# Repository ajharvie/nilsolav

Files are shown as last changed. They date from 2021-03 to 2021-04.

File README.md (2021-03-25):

# Nils Olav
A simple-to-build, low-profile, ortholinear keyboard named after a [famous penguin.](https://en.wikipedia.org/wiki/Nils_Olav) This keyboard is based around the Elite-C v4. It features a left-sided numpad, (useful for design work), 2U spacebar, a cute little penguin, and as low a parts count as possible to make it easy for individuals to build with very simple soldering tools.

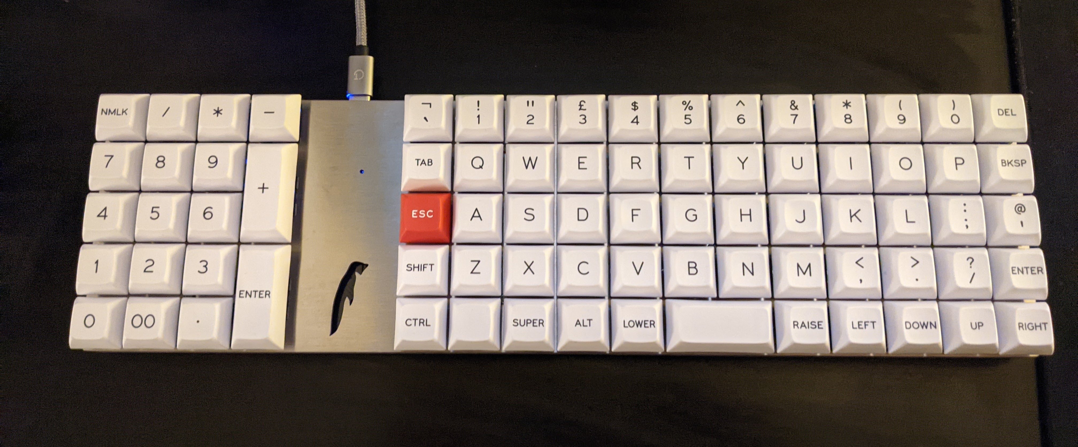
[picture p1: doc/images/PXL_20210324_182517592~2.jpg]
Image of keyboard


[A pre-compiled firmware hex](firmware/nilsolav_default.hex) (nilsolav_default.hex) is provided for my slightly unusual default keymap ([shown here](firmware/nilsolav/keymaps/default/keymap.c)). QMK users who wish to build their own keymap can do so using the source code provided in the [firmware](firmware) folder.

In the default keymap, double-tapping the numlock key toggles a layer where the numpad is transformed into a nav cluster.

Parts needed:
* PCB x1
* Bottom plate x1 
* Top plate x1 (1.5 mm thick)
* 8mm M2 standoffs x7
* M2 screws x14 (length depends on bottom plate thickness)
* Elite C v4 x1
* 2U stabiliser x1
* SOD-123 SMD diodes x77
* Your choice of MX switches x77
* Keycaps

[A build guide is included here.](doc/buildguide.md)

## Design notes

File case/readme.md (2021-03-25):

.dxf files for top and bottom plates that comprise the simple sandwich case. Mine is cut out of 3 mm brushed steel for the bottom plate, and 1.5 mm brushed steel for the top. 

To complete the case, you'll need some 8 mm (or longer) M2 standoffs, and 14 M2 screws (I used 7 x 4 mm and 7 x 6 mm)

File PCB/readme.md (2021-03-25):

KiCad files and gerbers for the keyboard. If you just want to make the keyboard PCBs, you just need the .zip of gerbers. I used PCBway but there are many good options for manufacturers.

If you're going to edit the pcb files, you'll need the following libraries:

ai03's MX footprint libary: https://github.com/ai03-2725/MX_Alps_Hybrid
Keebio-parts: https://github.com/keebio/Keebio-Parts.pretty
ai03's random-keyboard-parts: https://github.com/ai03-2725/random-keyboard-parts.pretty

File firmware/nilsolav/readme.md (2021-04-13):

# Nils Olav
A simple-to-build, low-profile, ortholinear keyboard named after a famous penguin. This keyboard is based around the Elite-C v4. It features a left-sided numpad, (useful for design work), 2U spacebar, and as low a parts count as possible to make it easy for individuals to build with very simple soldering tools.

Github repo with parts and build instructions: https://github.com/ajharvie/nilsolav

Parts needed:
* PCB x1
* Bottom plate x1 (I used 3 mm steel)
* Top plate x1 (1.5 mm thick)
* 8mm M2 standoffs x7
* M2 screws x14 (length depends on bottom plate thickness)
* Elite C v4 x1 (with castellated holes)
* 2U stabiliser x1
* SOD-123 SMD diodes x77
* Your choice of MX switches x77
* Keycaps

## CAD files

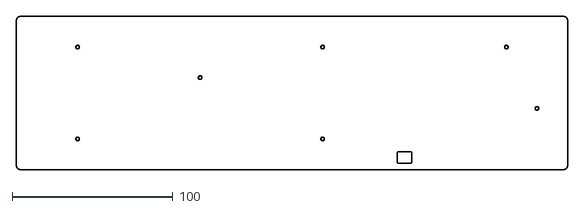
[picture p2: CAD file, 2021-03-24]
case/bottom.dxf
342.9 x 95.3

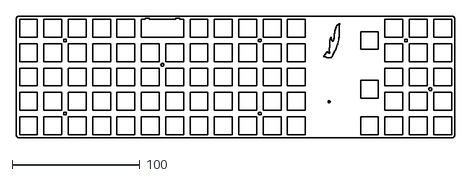
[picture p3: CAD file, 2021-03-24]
case/top.dxf
342.9 x 95.3

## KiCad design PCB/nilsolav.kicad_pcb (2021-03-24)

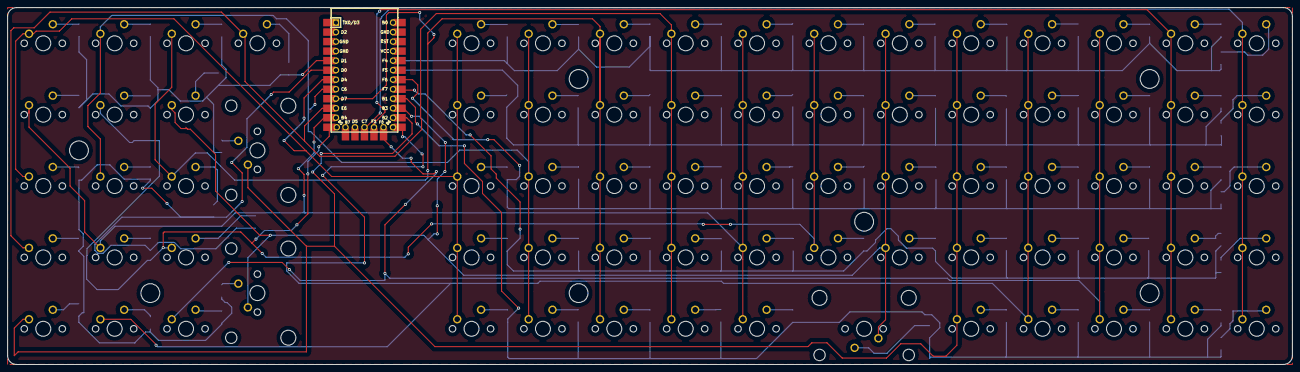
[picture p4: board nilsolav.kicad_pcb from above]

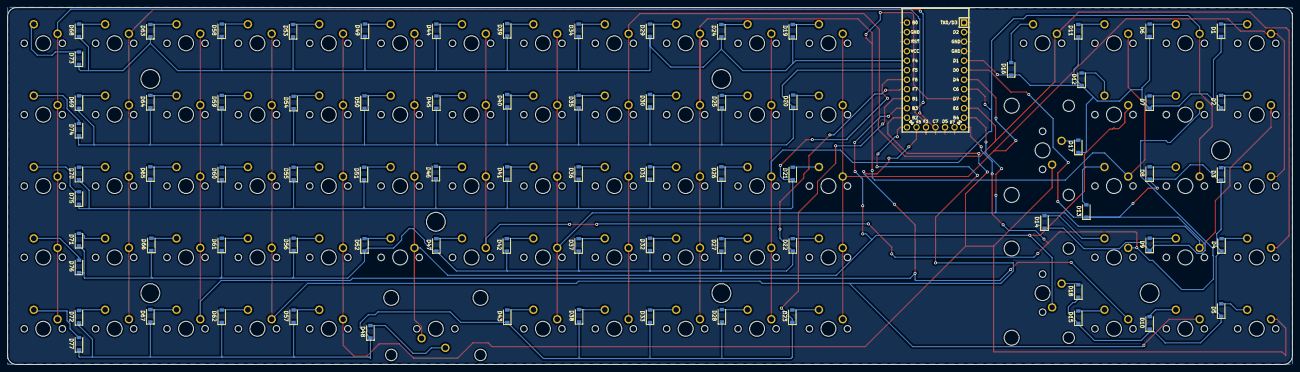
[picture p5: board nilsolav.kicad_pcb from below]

Board: 2 copper layers, 342.9 x 95.3 mm, 155 parts (77 on the bottom side), 97 nets.

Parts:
D1, D2, D3, D4, D5, D6, D7, D8, D9, D10, D11, D12, D13, D14, D15, D16, D17, D18, D19, D20, D21, D22, D23, D24, D25, D26, D27, D28, D29, D30, D31, D32, D33, D34, D35, D36, D37, D38, D39, D40, D41, D42, D43, D44, D45, D46, D47, D48, D49, D50, D51, D52, D53, D54, D55, D56, D57, D58, D59, D60, D61, D62, D63, D64, D65, D66, D67, D68, D69, D70, D71, D72, D73, D74, D75, D76, D77: D_Small; D_SOD-123
MX1, MX2, MX3, MX4, MX5, MX6, MX7, MX8, MX9, MX10, MX11, MX12, MX13, MX14, MX15, MX16, MX19, MX20, MX21, MX22, MX23, MX24, MX25, MX26, MX27, MX28, MX29, MX30, MX31, MX32, MX33, MX34, MX35, MX36, MX37, MX38, MX39, MX40, MX41, MX42, MX43, MX44, MX45, MX46, MX47, MX49, MX50, MX51, MX52, MX53, MX54, MX55, MX56, MX57, MX58, MX59, MX60, MX61, MX62, MX63, MX64, MX65, MX66, MX67, MX68, MX69, MX70, MX71, MX72, MX73, MX74, MX75, MX76, MX77: MX-NoLED; MXOnly-1U-NoLED
MX17, MX18, MX48: MX-NoLED; MXOnly-2U-NoLED
U1: Elite-C; Elite-C-castellated-29pin-holes

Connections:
unnamed: D1.2, MX1.2
unnamed: D2.2, MX2.2
unnamed: D3.2, MX3.2
unnamed: D4.2, MX4.2
unnamed: D5.2, MX5.2
unnamed: D6.2, MX6.2
unnamed: D7.2, MX7.2
unnamed: D8.2, MX8.2
unnamed: D9.2, MX9.2
unnamed: D10.2, MX10.2
unnamed: D11.2, MX11.2
unnamed: D12.2, MX12.2
unnamed: D13.2, MX13.2
unnamed: D14.2, MX14.2
unnamed: D15.2, MX15.2
unnamed: D16.2, MX16.2
unnamed: D17.2, MX17.2
unnamed: D18.2, MX18.2
unnamed: D19.2, MX19.2
unnamed: D20.2, MX20.2
unnamed: D21.2, MX21.2
unnamed: D22.2, MX22.2
unnamed: D23.2, MX23.2
unnamed: D24.2, MX24.2
unnamed: D25.2, MX25.2
unnamed: D26.2, MX26.2
unnamed: D27.2, MX27.2
unnamed: D28.2, MX28.2
unnamed: D29.2, MX29.2
unnamed: D30.2, MX30.2
unnamed: D31.2, MX31.2
unnamed: D32.2, MX32.2
unnamed: D33.2, MX33.2
unnamed: D34.2, MX34.2
unnamed: D35.2, MX35.2
unnamed: D36.2, MX36.2
unnamed: D37.2, MX37.2
unnamed: D38.2, MX38.2
unnamed: D39.2, MX39.2
unnamed: D40.2, MX40.2
unnamed: D41.2, MX41.2
unnamed: D42.2, MX42.2
unnamed: D43.2, MX43.2
unnamed: D44.2, MX44.2
unnamed: D45.2, MX45.2
unnamed: D46.2, MX46.2
unnamed: D47.2, MX47.2
unnamed: D48.2, MX48.2
unnamed: D49.2, MX49.2
unnamed: D50.2, MX50.2
unnamed: D51.2, MX51.2
unnamed: D52.2, MX52.2
unnamed: D53.2, MX53.2
unnamed: D54.2, MX54.2
unnamed: D55.2, MX55.2
unnamed: D56.2, MX56.2
unnamed: D57.2, MX57.2
unnamed: D58.2, MX58.2
unnamed: D59.2, MX59.2
unnamed: D60.2, MX60.2
unnamed: D61.2, MX61.2
unnamed: D62.2, MX62.2
unnamed: D63.2, MX63.2
unnamed: D64.2, MX64.2
unnamed: D65.2, MX65.2
unnamed: D66.2, MX66.2
unnamed: D67.2, MX67.2
unnamed: D68.2, MX68.2
unnamed: D69.2, MX69.2
unnamed: D70.2, MX70.2
unnamed: D71.2, MX71.2
unnamed: D72.2, MX72.2
unnamed: D73.2, MX73.2
unnamed: D74.2, MX74.2
unnamed: D75.2, MX75.2
unnamed: D76.2, MX76.2
unnamed: D77.2, MX77.2
col0: MX1.1, MX3.1, MX19.1, MX20.1, MX21.1, MX22.1, MX23.1, U1.7
col1: MX6.1, MX8.1, MX24.1, MX25.1, MX26.1, MX27.1, MX28.1, U1.8
col2: MX11.1, MX13.1, MX29.1, MX30.1, MX31.1, MX32.1, MX33.1, U1.9
col3: MX4.1, MX16.1, MX34.1, MX35.1, MX36.1, MX37.1, MX38.1, U1.10
col4: MX2.1, MX9.1, MX39.1, MX40.1, MX41.1, MX42.1, MX43.1, U1.11
col5: MX7.1, MX14.1, MX44.1, MX45.1, MX46.1, MX47.1, U1.12
col6: MX12.1, MX18.1, MX48.1, MX49.1, MX50.1, MX51.1, MX52.1, U1.15
col7: MX5.1, MX17.1, MX53.1, MX54.1, MX55.1, MX56.1, MX57.1, U1.14
col8: MX10.1, MX58.1, MX59.1, MX60.1, MX61.1, MX62.1, U1.13
col9: MX15.1, MX63.1, MX64.1, MX65.1, MX66.1, MX67.1, U1.29
col10: MX68.1, MX69.1, MX70.1, MX71.1, MX72.1, U1.28
col11: MX73.1, MX74.1, MX75.1, MX76.1, MX77.1, U1.27
gnd: U1.3, U1.4
row0: D19.1, D24.1, D29.1, D34.1, D39.1, D44.1, D49.1, D53.1, D58.1, D63.1, D68.1, D73.1, U1.20
row1: D20.1, D25.1, D30.1, D35.1, D40.1, D45.1, D50.1, D54.1, D59.1, D64.1, D69.1, D74.1, U1.19
row2: D21.1, D26.1, D31.1, D36.1, D41.1, D46.1, D51.1, D55.1, D60.1, D65.1, D70.1, D75.1, U1.18
row3: D22.1, D27.1, D32.1, D37.1, D42.1, D47.1, D52.1, D56.1, D61.1, D66.1, D71.1, D76.1, U1.17
row4: D23.1, D28.1, D33.1, D38.1, D43.1, D48.1, D57.1, D62.1, D67.1, D72.1, D77.1, U1.16
row5: D1.1, D2.1, D6.1, D7.1, D11.1, D12.1, D16.1, D17.1, U1.5
row6: D3.1, D4.1, D5.1, D8.1, D9.1, D10.1, D13.1, D14.1, D15.1, D18.1, U1.6

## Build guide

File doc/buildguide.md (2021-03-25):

Parts you need to hand: 
* PCB x1
* Bottom plate x1
* Top plate x1 (1.5 mm thick)
* 8mm M2 standoffs x7
* M2 screws x14 (length depends on bottom plate thickness)
* Elite C v4 x1
* 2U stabiliser x1
* SOD-123 SMD diodes x77
* Your choice of MX switches x77
* Keycaps

1) Before you start, check that the Elite-C works by flashing it with the default firmware. Nothing worse than soldering everything together then realising your controller is borked!
2) Start the build by soldering the diodes onto the bottom side of the PCB in the marked positions. The little bar on the cathode side of the diode should go against the "closed" side of the marking, and the anode against the "open" side, as shown:

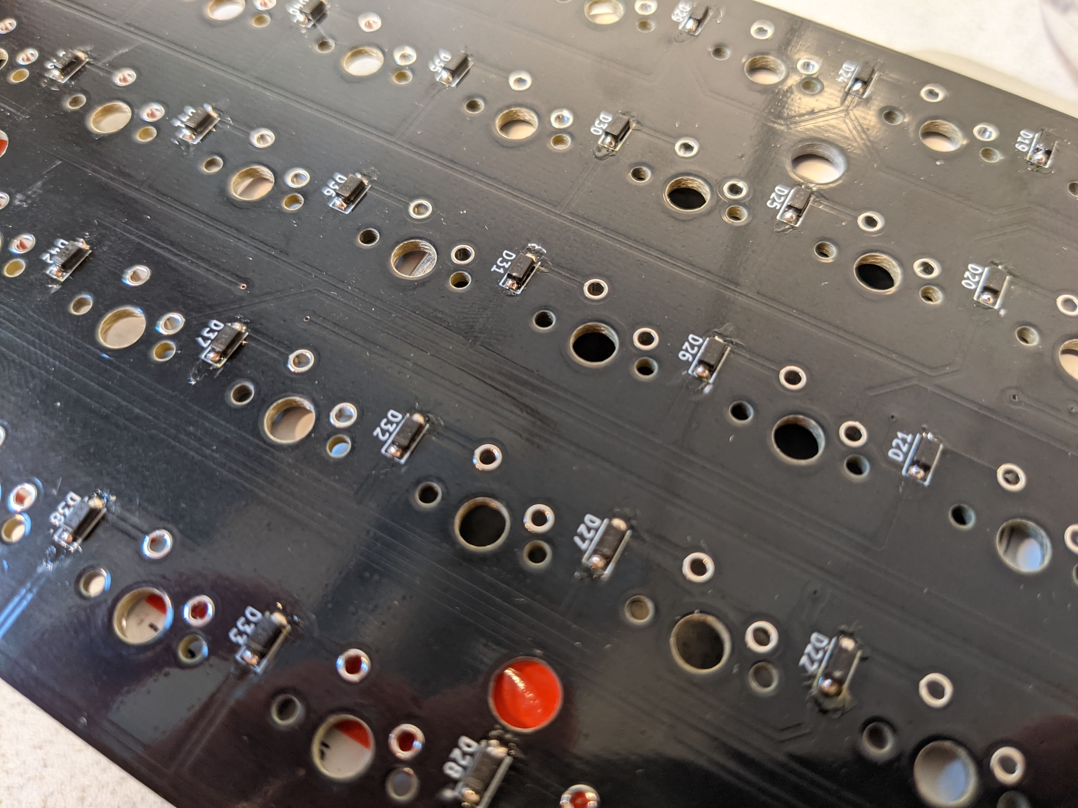
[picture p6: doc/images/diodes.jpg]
Soldering diodes


The easiest way to solder the diodes on with an iron is to add solder to one of the pads, then with the iron still in contact with the molten solder, slide the diode into place. Then remove the iron. You can then solder the second terminal to the other pad. A bit of flux added to the pads before you start can help but is not necessary if you have decent flux-cored solder.

3) Solder the Elite-C in place, flat onto the PCB, using the castellated holes, as pictured. This is done similarly to the diodes. Sparkfun has a nice tutorial [here](https://learn.sparkfun.com/tutorials/how-to-solder-castellated-mounting-holes/all) on how to do it.

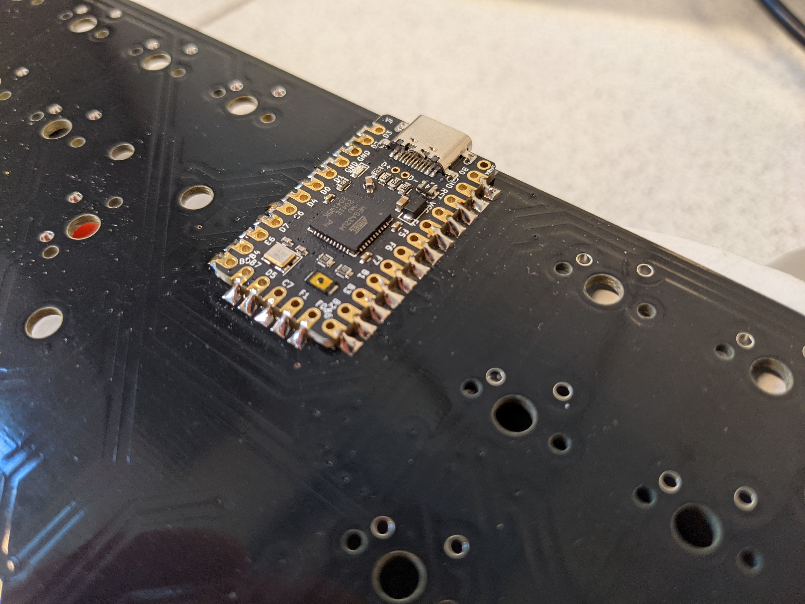
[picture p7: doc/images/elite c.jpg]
Soldering controller


4) Plug in your PCB and test it by shorting the pads for each switch and checking that the right keypress is registered. If a key is not working, it's most likely you've got a bad solder joint on the diode.
5) Add your 2U stabiliser to the PCB, then mount the switches by pushing them into their spaces on the top plate and into the PCB. If you've got it right, the reset button on the elite-c should line up with the little hole in the top plate. When you're happy that everything's seated correctly, solder the switches into their sockets.
6) Prepare the bottom plate with 7 8 mm-long M2 standoffs and M2 screws, as pictured:

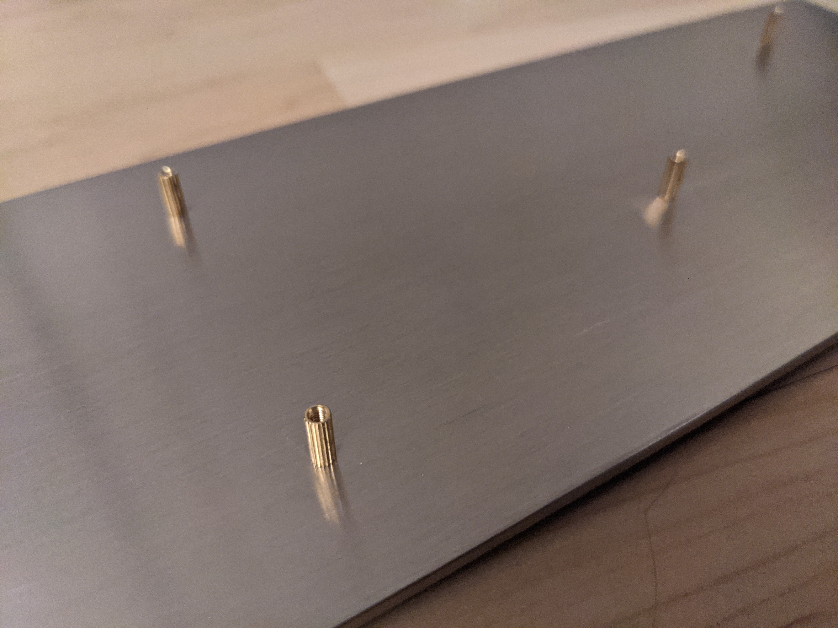
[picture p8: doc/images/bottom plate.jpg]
Standoffs


7) Fasten the plates together using 7 more M2 screws. What you now have should look like this:

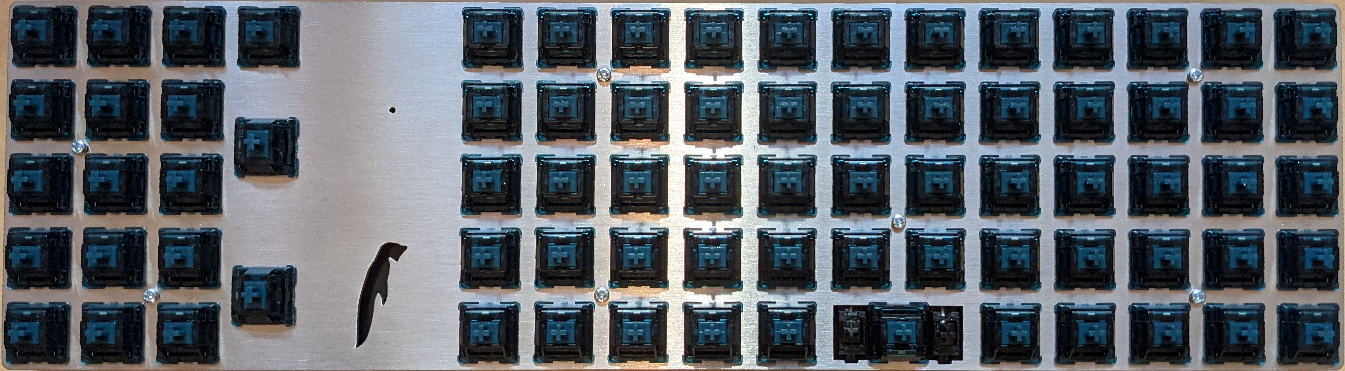
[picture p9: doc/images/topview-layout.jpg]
Together


8) You're nearly done! Add your keycaps, flash your firmware and enjoy! 

Assembled

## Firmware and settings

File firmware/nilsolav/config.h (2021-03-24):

/*

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
You should have received a copy of the GNU General Public License
along with this program.  If not, see <http://www.gnu.org/licenses/>.
*/

#pragma once

#include "config_common.h"

/* USB Device descriptor parameter */
#define VENDOR_ID       0xFEED
#define PRODUCT_ID      0xF4BA
//#define PRODUCT_ID      0xNOOT
#define DEVICE_VER      0x0001
#define MANUFACTURER    Andrew Harvie
#define PRODUCT         Brigadier Sir Nils Olav III
#define DESCRIPTION     q.m.k. keyboard firmware for NilsOlav
#define TAPPING_TERM 200

/* key matrix size */
#define MATRIX_ROWS 7
#define MATRIX_COLS 12

/*
 * Keyboard Matrix Assignments
 *
 * Change this to how you wired your keyboard
 * COLS: AVR pins used for columns, left to right
 * ROWS: AVR pins used for rows, top to bottom
 * DIODE_DIRECTION: COL2ROW = COL = Anode (+), ROW = Cathode (-, marked on diode)
 *                  ROW2COL = ROW = Anode (+), COL = Cathode (-, marked on diode)
 *
*/
#define MATRIX_ROW_PINS { F4, F5, F6, F7, B1, D1, D0  }
#define MATRIX_COL_PINS { D4, C6, D7, E6, B4, B5, B3, B2, B6, F0, F1, C7 }

/* COL2ROW or ROW2COL */
#define DIODE_DIRECTION COL2ROW


/* Debounce reduces chatter (unintended double-presses) - set 0 if debouncing is not needed */
#define DEBOUNCING_DELAY 5

/* Mechanical locking support. Use KC_LCAP, KC_LNUM or KC_LSCR instead in keymap */
//#define LOCKING_SUPPORT_ENABLE
/* Locking resynchronize hack */
#define LOCKING_RESYNC_ENABLE

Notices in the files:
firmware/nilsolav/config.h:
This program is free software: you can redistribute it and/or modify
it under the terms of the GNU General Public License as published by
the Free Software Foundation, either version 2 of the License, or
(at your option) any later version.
